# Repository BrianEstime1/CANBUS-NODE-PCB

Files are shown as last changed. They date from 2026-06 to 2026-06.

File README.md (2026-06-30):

# CANBUS-NODE-PCB



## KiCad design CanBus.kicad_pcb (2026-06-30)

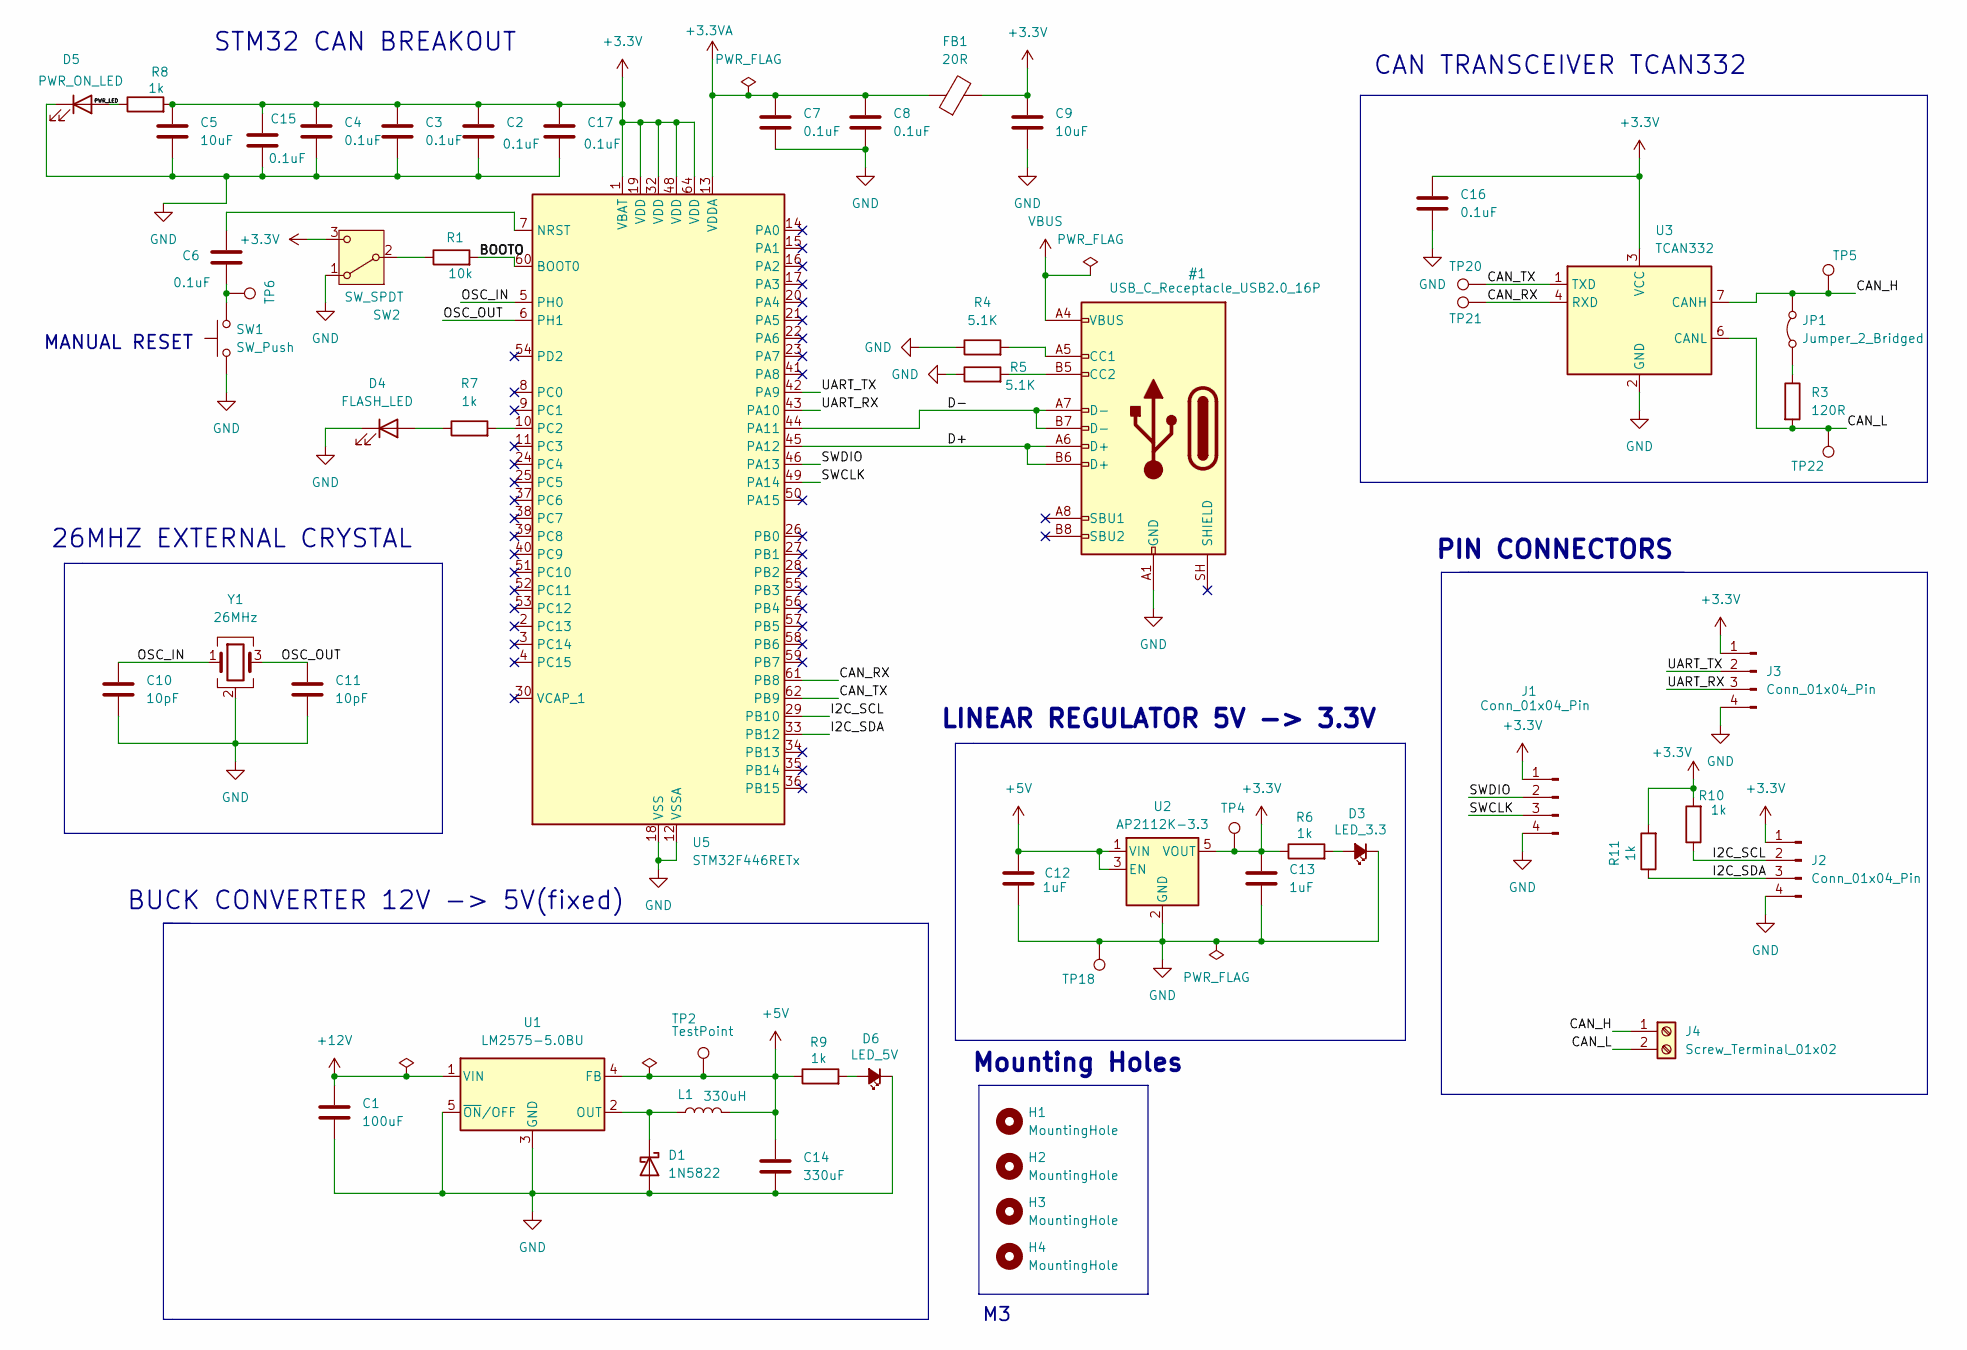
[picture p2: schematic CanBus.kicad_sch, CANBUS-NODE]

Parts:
C1: 100uF; C_Elec_8x10.2; LCSC C176672
C2, C3, C4, C6, C7, C8, C15, C16, C17: 0.1uF; C_0603_1608Metric
C5, C9: 10uF; C_0603_1608Metric
C10, C11: 10pF; C_0603_1608Metric
C12, C13: 1uF; C_0603_1608Metric
C14: 330uF; C_Elec_10x10.2; LCSC C176675
D1: 1N5822; D_DO-201AD_P15.24mm_Horizontal; LCSC C2476
D3: LED_3.3; LED_0603_1608Metric; LCSC C84256
D4: FLASH_LED; LED_0603_1608Metric; LCSC C84256
D5: PWR_ON_LED; LED_0603_1608Metric; LCSC C84256
D6: LED_5V; LED_0603_1608Metric; LCSC C84256
FB1: 20R; L_0603_1608Metric; LCSC C394467
H1, H2, H3, H4: MountingHole; MountingHole_3.2mm_M3
J1, J2, J3: Conn_01x04_Pin; PinHeader_1x04_P2.54mm_Vertical
J4: Screw_Terminal_01x02; TerminalBlock_Phoenix_MKDS-1,5-2-5.08_1x02_P5.08mm_Horizont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
JP1: Jumper_2_Bridged; SolderJumper-2_P1.3mm_Bridged_Pad1.0x1.5mm
L1: 330uH; L_12x12mm_H6mm; LCSC C2453076
R1: 10k; R_0603_1608Metric
R3: 120R; R_0603_1608Metric
R4, R5: 5.1K; R_0603_1608Metric
R6, R7, R8, R9, R10, R11: 1k; R_0603_1608Metric
SW1: SW_Push; SW_SPST_TL3305B
SW2: SW_SPDT; SW_SPDT_PCM12
TP2, TP4, TP6, TP18, TP20, TP21: TestPoint; TestPoint_Pad_1.0x1.0mm
TP5, TP22: TestPoint; TestPoint_Loop_D1.80mm_Drill1.0mm_Beaded
U1: LM2575-5.0BU; TO-263-5_TabPin3
U2: AP2112K-3.3; SOT-23-5; LCSC C51118
U3: TCAN332; TSOT-23-8; LCSC C544741
U5: STM32F446RETx; LQFP-64_10x10mm_P0.5mm; LCSC C69336
Y1: 26MHz; Crystal_SMD_Abracon_ABM8G-4Pin_3.2x2.5mm; LCSC C7065088

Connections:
+3.3V: C2.1, C3.1, C4.1, C5.1, C9.1, C13.1, C15.1, C16.1, C17.1, FB1.2, J1.1, J2.1, J3.1, R6.1, R8.2, R10.2, R11.2, SW2.3 (C), TP4.1 (1_1), U2.5 (VOUT), U3.3 (VCC), U5.1 (VBAT), U5.19 (VDD), U5.32 (VDD), U5.48 (VDD), U5.64 (VDD)
+3.3VA: C7.1, C8.1, FB1.1, U5.13 (VDDA)
+5V: C12.1, C14.1, L1.2, R9.1, TP2.1 (1_1), U1.4 (FB), U2.1 (VIN), U2.3 (EN)
+12V: C1.1, U1.1 (VIN)
/BOOTO: R1.2, U5.60 (BOOT0)
/CAN_H: J4.1, JP1.2 (B), TP5.1 (1_1), U3.7 (CANH)
/CAN_L: J4.2, R3.2, TP22.1 (1_1), U3.6 (CANL)
/CAN_RX: TP21.1 (1_1), U3.4 (RXD), U5.61 (PB8)
/CAN_TX: TP20.1 (1_1), U3.1 (TXD), U5.62 (PB9)
/I2C_SCL: J2.2, R10.1, U5.29 (PB10)
/I2C_SDA: J2.3, R11.1, U5.33 (PB12)
/OSC_IN: C10.1, U5.5 (PH0), Y1.1
/OSC_OUT: C11.1, U5.6 (PH1), Y1.3
/PWR_LED: D5.2 (A), R8.1
/SWCLK: J1.3, U5.49 (PA14)
/SWDIO: J1.2, U5.46 (PA13)
/UART_RX: J3.3, U5.43 (PA10)
/UART_TX: J3.2, U5.42 (PA9)
unnamed: C6.2, SW1.2, TP6.1 (1_1)
unnamed: D1.1 (K), L1.1, U1.2 (OUT)
unnamed: D3.2 (A), R6.2
unnamed: D4.2 (A), R7.1
unnamed: D6.2 (A), R9.2
unnamed: JP1.1 (A), R3.1
unnamed: R1.1, SW2.2 (B)
unnamed: C6.1, U5.7 (NRST)
unnamed: R7.2, U5.10 (PC2)

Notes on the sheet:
Mounting Holes
MANUAL RESET
26MHZ EXTERNAL CRYSTAL
STM32 CAN BREAKOUT
LINEAR REGULATOR 5V -> 3.3V
CAN TRANSCEIVER TCAN332
BUCK CONVERTER 12V -> 5V(fixed)
PIN CONNECTORS

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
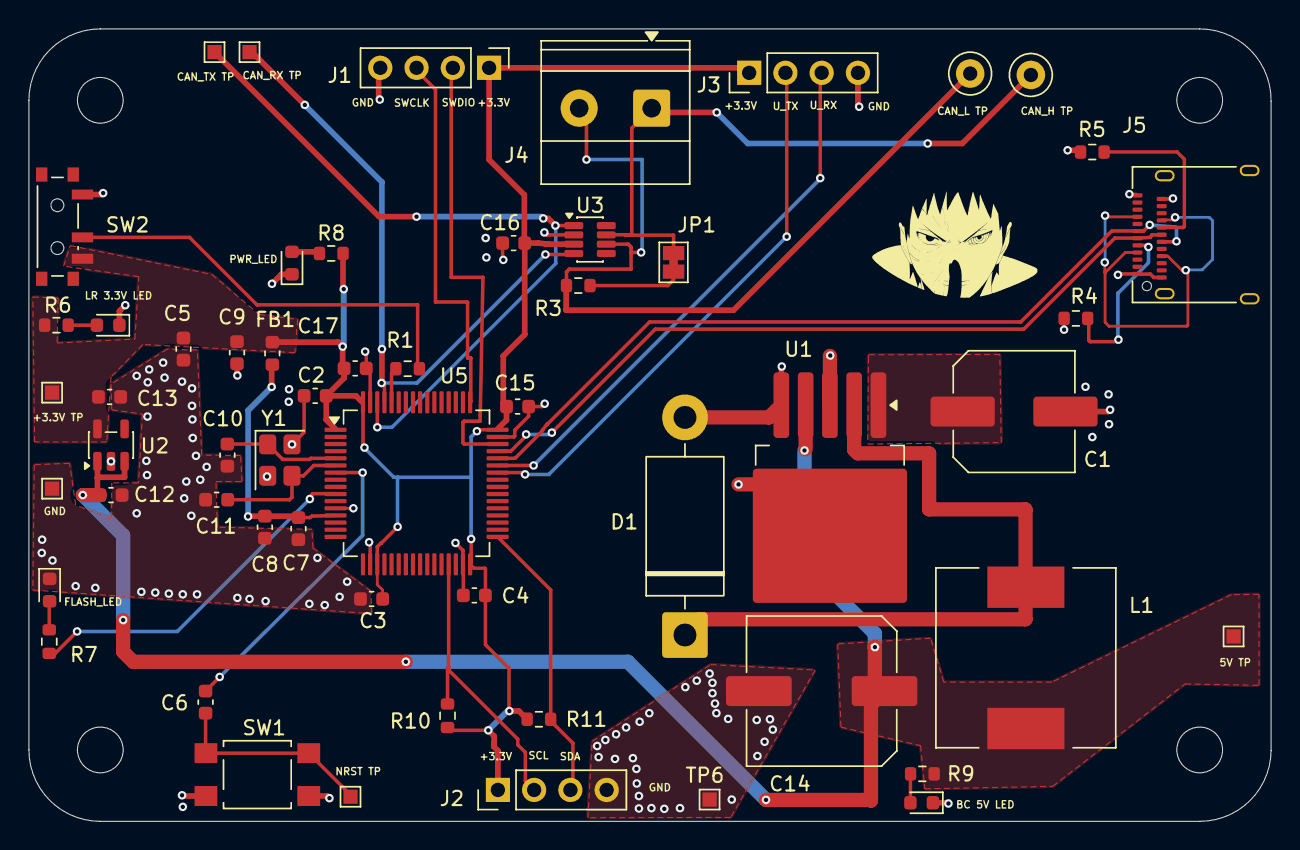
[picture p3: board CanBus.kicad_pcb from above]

Board: 4 copper layers, 87.0 x 55.5 mm, 60 parts (0 on the bottom side), 33 nets.

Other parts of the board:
J5: USB_C_Receptacle_USB2.0_16P; USB_C_Receptacle_Amphenol_12401610E4-2A
TP6#2: TestPoint; TestPoint_Pad_1.0x1.0mm

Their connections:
VBUS: J5.A4 (VBUS), J5.A9 (VBUS), J5.B4 (VBUS), J5.B9 (VBUS)

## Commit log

2026-06-30 Add CAN Bus Node PCB KiCad project files and Gerber outputs
    - KiCad 10.0 project files (kicad_pcb, kicad_sch, kicad_pro, kicad_prl)
    - Full Gerber fabrication set: F.Cu, B.Cu, In1.Cu, In2.Cu, masks, silkscreen, edge cuts
    - Drill files (PTH + NPTH) and component placement CSV
    - 4-layer STM32F446RET6 CAN bus breakout board with TCAN332 transceiver
    [CanBus-B_Cu.gbl, CanBus-B_Mask.gbs, CanBus-B_Paste.gbp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]
2026-06-30 Update README with images for CANBUS-NODE-PCB
    Added images to README for better visualization.
